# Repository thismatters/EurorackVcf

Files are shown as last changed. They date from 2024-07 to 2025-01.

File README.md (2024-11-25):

# Voltage Controlled Filter

The Voltage Controlled Filter (VCF) filters incoming audio signals to the degree specified by the control voltages. This implementation uses a transistor ladder similar to that found in Moog synthesizers with both a cutoff frequency and a resonator control.

The circuit here is based on the [MiniMoog VCF](https://yusynth.net/Modular/EN/MOOGVCF/index.html) with minor tweaks to make it more Eurorack friendly. The changes I've made are thus:
* Selected resistors appropriate for +/-12V rails,
* Added polarity protection so that a backward power header doesn't fry anything (twin series schotty diodes: BAT54SL),
* Selected a modern dual NPN diode package for matched transistors,
* Full surface mount design.

The Yusynth page is a treasure trove of information about this circuit that I am too amateur to claim as my own; please read that outstanding page before using this circuit. The page provides many details and other implementations of this circuit that you may find suitable.

The KiCAD project here uses the library/footprints [found in my companion repo](https://github.com/thismatters/EurorackKiCAD).

## Width

8hp on a standard 3U rack.

## Inputs

Potentiometer labeled `cutoff` controls the cutoff frequency, which is also augmented by the `cv1` input and potentiometer. Two other CV inputs `cv2` and `cv3` combine with `cv1` and the `cutoff` knob to set the frequency. An additional potentiometer for setting the `emph`asis. Two audio signal inputs, `in1` and `in2` are adjusted for level by twin potentiometers and combine as the audio input to the filter.

## Output

A single output labeled `out` yields the filtered audio signal.

## Adjustment

### Volt per Octave tracking

1. Set the `cutoff` knob to its minimum setting (counterclockwise).
1. Set the `emph` knob to its minimum setting (counterclockwise).
1. Apply 0V to `cv2`.
1. Measure 0mV at the test point `TP1`.
1. Apply 1V to `cv2`.
1. Adjust RV6 to measure 18.2mV at `TP1`.
1. Apply 5V to `cv2`.
1. Adjust RV6 to measure 91mV at `TP1`.
1. Set the `emph` knob to its maximum setting (auto oscillation).
1. Connect a keyboard to `cv2` and play a scale.
1. Adjust RV6 to achieve good chromatic tracking.

### Frequency Range

1. Apply a 32Hz sine wave to `in1`.
1. Set the `emph` knob to its minimum setting.
1. Set the `cutoff` knob to its minimum setting.
1. Adjust RV7 until the 32Hz tone is muted.

### Emphasis

1. Adjust RV8 in order to reach auto-oscillation near 95% of the full range of the `emph` potentiometer.

## Vendors

There are part numbers in the [BOM](moog-vcf.csv) for many of the parts (not for basic passives though) at the following vendors:

* [Mouser](https://www.mouser.com): Needs no introduction. Get your ICs from here (or [digikey](https://www.digikey.com)).
* [Tayda Electronics](https://www.taydaelectronics.com/): Good supplier for passive components; audio jacks, and potentiometers. Their audio jacks are slightly smaller than the thonkiconn from thonk.
* [Love My Switches](https://lovemyswitches.com/): Has [really good knobs](https://lovemyswitches.com/anodized-aluminum-knob-the-lo-fi-1-4-smooth-shaft-12-5mm-od/) to go on those potentiometers!
* [OSHPark](https://oshpark.com/): Fast and (relatively) cheap PCB manufacturer. The [V0 Circuit](https://oshpark.com/shared_projects/SO7swty4) works pretty well.

## Known Bugs

### v0

* Vias on Q5 (B1 and B2) block pads. (doesn't prohibit function)
* C8 hole pitch too narrow (should be 3mm)

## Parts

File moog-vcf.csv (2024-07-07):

# | Reference | Qty | Value | Footprint | DNP | Vendor | PartNum
1 | C1, C2 | 2 | 22u 35V | Capacitor_THT:CP_Radial_D5.0mm_P2.50mm
2 | C3, C11, C12 | 3 | 10u | Capacitor_THT:CP_Radial_D5.0mm_P2.50mm
3 | C4, C5, C6, C7 | 4 | 47n | Capacitor_SMD:C_0805_2012Metric
4 | C8 | 1 | 220u | Capacitor_THT:CP_Radial_D8.0mm_P2.50mm
5 | C9, C10 | 2 | 220n | Capacitor_SMD:C_0805_2012Metric
6 | C13 | 1 | 100n | Capacitor_SMD:C_0805_2012Metric
7 | C14 | 1 | 100p | Capacitor_SMD:C_0805_2012Metric
8 | D1, D2 | 2 | BAT54S | Package_TO_SOT_SMD:SOT-23 |  | Mouser | 863-BAT54SLT1G
9 | J1 | 1 | Conn_02x05_Odd_Even | Eurorack:PinHeader_2x05_P2.54mm_Vertical |  | Tayda | A-2939
10 | J2, J3, J4, J5, J6, J7 | 6 | AudioJack2_SwitchT | Eurorack:AudioJack2_Tayda_A-2566 |  | Tayda | A-2566
11 | Q1, Q2, Q3, Q4, Q5, Q6, Q7 | 7 | BCM847 | Package_SO:TSOP-6_1.65x3.05mm_P0.95mm |  | Mouser | 771-BCM847DS135
12 | Q8 | 1 | BC557 | Package_TO_SOT_THT:TO-92L_Inline_Wide |  | Mouser | 637-BC557B
13 | Q9 | 1 | BC547 | Package_TO_SOT_THT:TO-92L_Inline_Wide |  | Mouser | 637-BC547C
14 | R1, R2 | 2 | 10 | Resistor_SMD:R_0805_2012Metric
15 | R3, R4, R32 | 3 | 120K | Resistor_SMD:R_0805_2012Metric
16 | R5, R31 | 2 | 56K | Resistor_SMD:R_0805_2012Metric
17 | R6 | 1 | 10K | Resistor_SMD:R_0805_2012Metric
18 | R7, R8, R9, R13 | 4 | 100K | Resistor_SMD:R_0805_2012Metric
19 | R10 | 1 | 150K | Resistor_SMD:R_0805_2012Metric
20 | R11 | 1 | 1.8K | Resistor_SMD:R_0805_2012Metric
21 | R12, R15 | 2 | 470 | Resistor_SMD:R_0805_2012Metric
22 | R14 | 1 | 220 | Resistor_SMD:R_0805_2012Metric
23 | R16, R26, R28, R33 | 4 | 1K | Resistor_SMD:R_0805_2012Metric
24 | R17, R19, R20, R21 | 4 | 150 | Resistor_SMD:R_0805_2012Metric
25 | R18, R22 | 2 | 330 | Resistor_SMD:R_0805_2012Metric
26 | R23, R30 | 2 | 47K | Resistor_SMD:R_0805_2012Metric
27 | R24, R27 | 2 | 220K | Resistor_SMD:R_0805_2012Metric
28 | R25 | 1 | 22 | Resistor_SMD:R_0805_2012Metric
29 | R29 | 1 | 180 | Resistor_SMD:R_0805_2012Metric
30 | R34 | 1 | 680 | Resistor_SMD:R_0805_2012Metric
31 | RV1, RV2 | 2 | A50K | Eurorack:Potentiometer_RV16AF-41-15R1 |  | Tayda | A-4182
32 | RV3 | 1 | B50K | Eurorack:Potentiometer_RV16AF-41-15R1 |  | Tayda | A-2393
33 | RV4 | 1 | B10K | Eurorack:Potentiometer_RV16AF-41-15R1 |  | Tayda | A-2969
34 | RV5 | 1 | C50K | Eurorack:Potentiometer_RV16AF-41-15R1 |  | Tayda | A-4181
35 | RV6 | 1 | 500 | Potentiometer_THT:Potentiometer_Bourns_3296W_Vertical
36 | RV7 | 1 | 10K | Potentiometer_THT:Potentiometer_Bourns_3296W_Vertical
37 | RV8 | 1 | 1K | Potentiometer_THT:Potentiometer_Bourns_3296W_Vertical
38 | TP1 | 1 | TestPoint | TestPoint:TestPoint_THTPad_D2.0mm_Drill1.0mm
39 | U1 | 1 | TL072 | Package_SO:SOIC-8_3.9x4.9mm_P1.27mm |  | Mouser | 595-TL072CDR

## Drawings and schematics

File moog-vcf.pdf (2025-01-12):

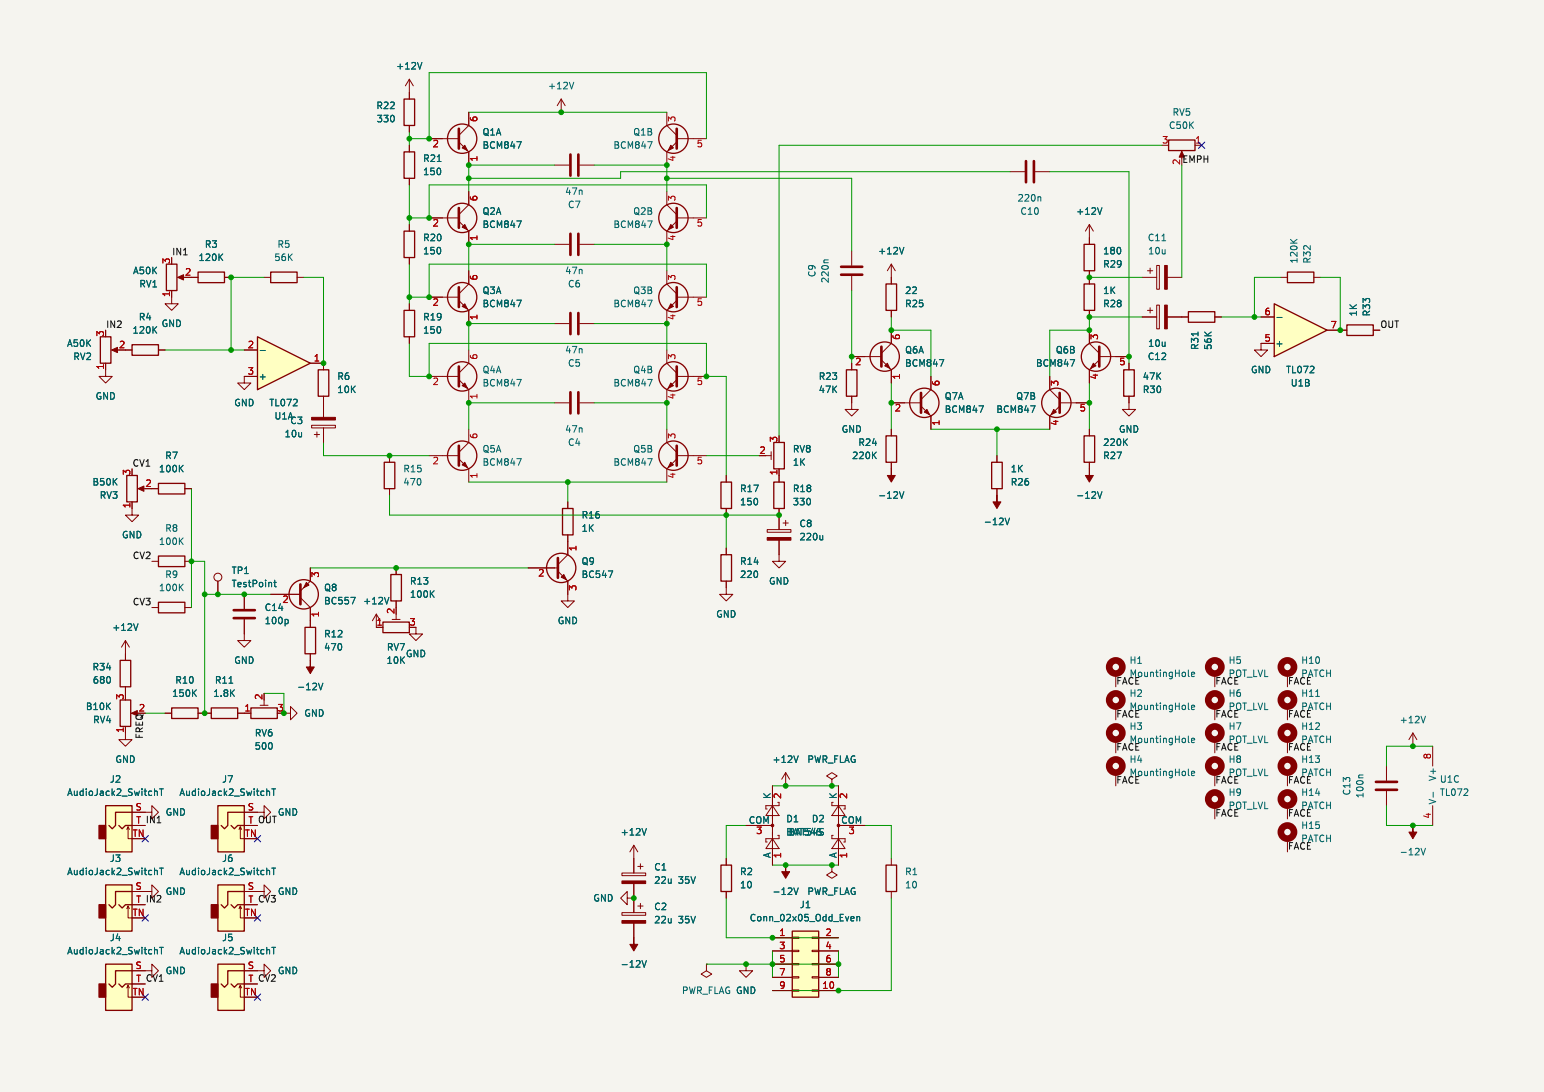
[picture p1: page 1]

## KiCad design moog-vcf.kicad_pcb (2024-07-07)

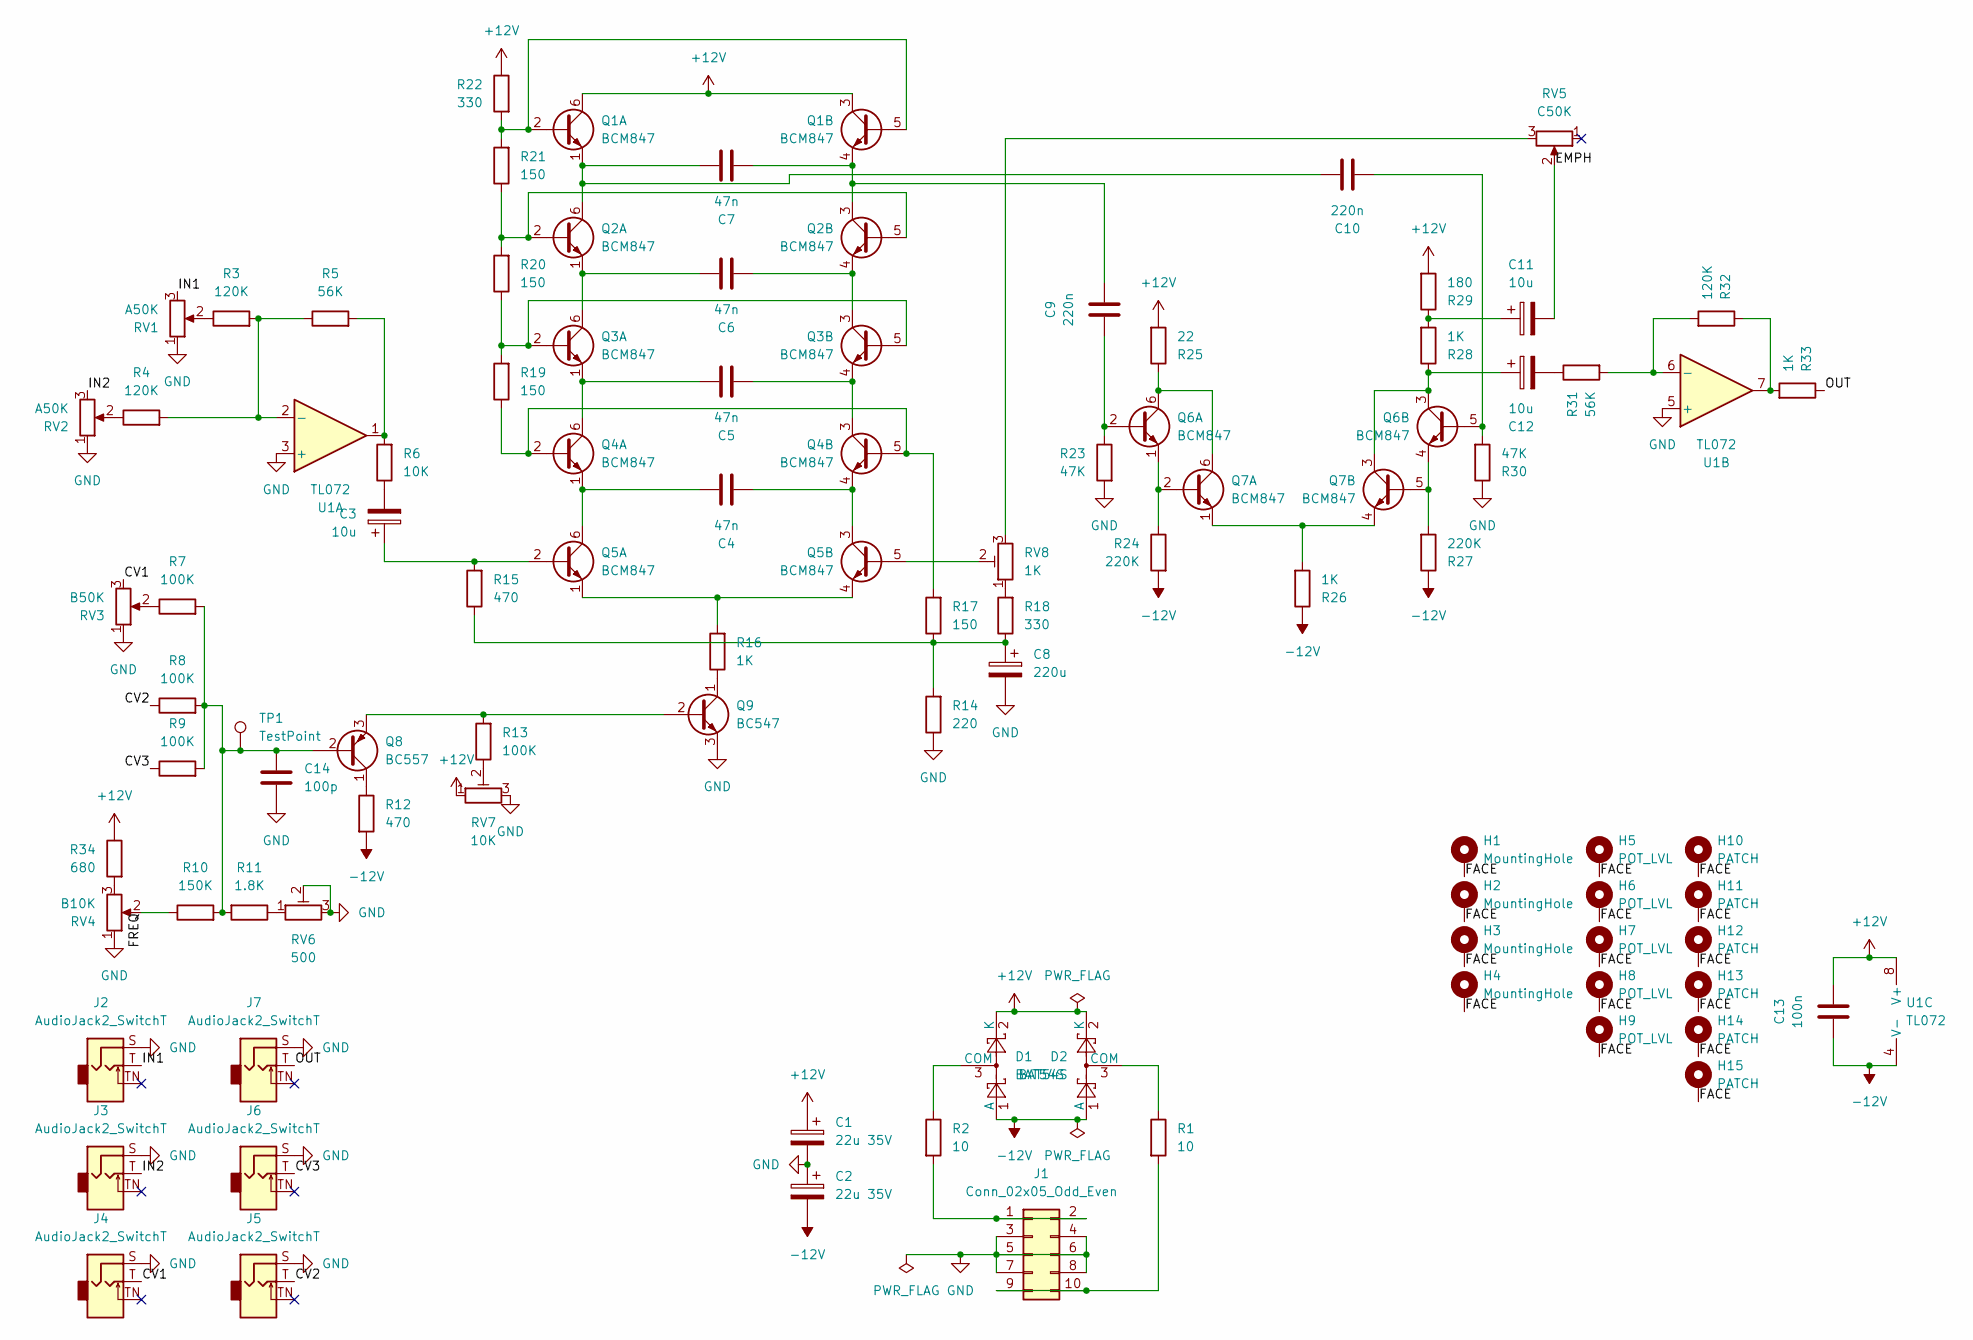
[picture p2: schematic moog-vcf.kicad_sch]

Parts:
C1, C2: 22u 35V; CP_Radial_D5.0mm_P2.50mm
C3, C11, C12: 10u; CP_Radial_D5.0mm_P2.50mm
C4, C5, C6, C7: 47n; C_0805_2012Metric
C8: 220u; CP_Radial_D8.0mm_P2.50mm
C9, C10: 220n; C_0805_2012Metric
C13: 100n; C_0805_2012Metric
C14: 100p; C_0805_2012Metric
D1, D2: BAT54S; SOT-23; PartNum 863-BAT54SLT1G
H1, H2, H3, H4: MountingHole; Mech-MountingHole
H5, H6, H7, H8, H9: POT_LVL; Mech-Potentiometer-Hole_level
H10, H11, H12, H13, H14: PATCH; Mech-AudioJack-Hole
H15: PATCH; Mech-AudioJack-Hole-Output
J1: Conn_02x05_Odd_Even; PinHeader_2x05_P2.54mm_Vertical; PartNum A-2939
J2, J3, J4, J5, J6, J7: AudioJack2_SwitchT; AudioJack2_Tayda_A-2566; PartNum A-2566
Q1, Q2, Q3, Q4, Q5, Q6, Q7: BCM847; TSOP-6_1.65x3.05mm_P0.95mm; PartNum 771-BCM847DS135
Q8: BC557; TO-92L_Inline_Wide; PartNum 637-BC557B
Q9: BC547; TO-92L_Inline_Wide; PartNum 637-BC547C
R1, R2: 10; R_0805_2012Metric
R3, R4, R32: 120K; R_0805_2012Metric
R5, R31: 56K; R_0805_2012Metric
R6: 10K; R_0805_2012Metric
R7, R8, R9, R13: 100K; R_0805_2012Metric
R10: 150K; R_0805_2012Metric
R11: 1.8K; R_0805_2012Metric
R12, R15: 470; R_0805_2012Metric
R14: 220; R_0805_2012Metric
R16, R26, R28, R33: 1K; R_0805_2012Metric
R17, R19, R20, R21: 150; R_0805_2012Metric
R18, R22: 330; R_0805_2012Metric
R23, R30: 47K; R_0805_2012Metric
R24, R27: 220K; R_0805_2012Metric
R25: 22; R_0805_2012Metric
R29: 180; R_0805_2012Metric
R34: 680; R_0805_2012Metric
RV1, RV2: A50K; Potentiometer_RV16AF-41-15R1; PartNum A-4182
RV3: B50K; Potentiometer_RV16AF-41-15R1; PartNum A-2393
RV4: B10K; Potentiometer_RV16AF-41-15R1; PartNum A-2969
RV5: C50K; Potentiometer_RV16AF-41-15R1; PartNum A-4181
RV6: 500; Potentiometer_Bourns_3296W_Vertical
RV7: 10K; Potentiometer_Bourns_3296W_Vertical
RV8: 1K; Potentiometer_Bourns_3296W_Vertical
TP1: TestPoint; TestPoint_THTPad_D2.0mm_Drill1.0mm
U1: TL072; SOIC-8_3.9x4.9mm_P1.27mm; PartNum 595-TL072CDR

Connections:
+12V: C1.1, C13.1, D1.2 (K), D2.2 (K), Q1.3 (C2), Q1.6 (C1), R22.1, R25.2, R29.2, R34.1, RV7.1, U1.8 (V+)
-12V: C2.2, C13.2, D1.1 (A), D2.1 (A), R12.2, R24.2, R26.1, R27.1, U1.4 (V-)
/CV1: J4.T, RV3.3
/CV2: J5.T, R8.1
/CV3: J6.T, R9.1
/EMPH: C11.2, RV5.2
/FACE: H1.1, H2.1, H3.1, H4.1, H5.1, H6.1, H7.1, H8.1, H9.1, H10.1, H11.1, H12.1, H13.1, H14.1, H15.1
/FREQ: R10.1, RV4.2
/IN1: J2.T, RV1.3
/IN2: J3.T, RV2.3
/OUT: J7.T, R33.1
GND: C1.2, C2.1, C8.2, C14.2, J1.3, J1.4, J1.5, J1.6, J1.7, J1.8, J2.S, J3.S, J4.S, J5.S, J6.S, J7.S, Q9.3 (E), R14.1, R23.2, R30.1, RV1.1, RV2.1, RV3.1, RV4.1, RV6.2, RV6.3, RV7.3, U1.3 (+), U1.5 (+)
unnamed: C3.2, R6.1
unnamed: C8.1, R14.2, R15.1, R17.1, R18.1
unnamed: C11.1, R28.2, R29.1
unnamed: C12.2, R31.1
unnamed: D1.3 (COM), R2.1
unnamed: D2.3 (COM), R1.1
unnamed: J1.1, J1.2, R2.2
unnamed: J1.9, J1.10, R1.2
unnamed: Q1.2 (B1), Q1.5 (B2), R21.2, R22.2
unnamed: C7.1, C10.1, Q1.1 (E1), Q2.6 (C1)
unnamed: C7.2, C9.1, Q1.4 (E2), Q2.3 (C2)
unnamed: Q2.2 (B1), Q2.5 (B2), R20.2, R21.1
unnamed: C6.1, Q2.1 (E1), Q3.6 (C1)
unnamed: C6.2, Q2.4 (E2), Q3.3 (C2)
unnamed: Q3.2 (B1), Q3.5 (B2), R19.2, R20.1
unnamed: C5.1, Q3.1 (E1), Q4.6 (C1)
unnamed: C5.2, Q3.4 (E2), Q4.3 (C2)
unnamed: Q4.2 (B1), Q4.5 (B2), R17.2, R19.1
unnamed: C4.1, Q4.1 (E1), Q5.6 (C1)
unnamed: C4.2, Q4.4 (E2), Q5.3 (C2)
unnamed: C3.1, Q5.2 (B1), R15.2
unnamed: Q5.1 (E1), Q5.4 (E2), R16.2
unnamed: Q5.5 (B2), RV8.2
unnamed: C9.2, Q6.2 (B1), R23.1
unnamed: Q6.6 (C1), Q7.6 (C1), R25.1
unnamed: Q6.1 (E1), Q7.2 (B1), R24.1
unnamed: C10.2, Q6.5 (B2), R30.2
unnamed: C12.1, Q6.3 (C2), Q7.3 (C2), R28.1
unnamed: Q6.4 (E2), Q7.5 (B2), R27.2
unnamed: Q7.1 (E1), Q7.4 (E2), R26.2
unnamed: C14.1, Q8.2 (B), R7.2, R8.2, R9.2, R10.2, R11.2, TP1.1
unnamed: Q8.1 (C), R12.1
unnamed: Q8.3 (E), Q9.2 (B), R13.2
unnamed: Q9.1 (C), R16.1
unnamed: R3.1, RV1.2
unnamed: R4.1, RV2.2
unnamed: R5.2, R6.2, U1.1
unnamed: R7.1, RV3.2
unnamed: R11.1, RV6.1
unnamed: R13.1, RV7.2
unnamed: R18.2, RV8.1
unnamed: R32.1, R33.2, U1.7
unnamed: R34.2, RV4.3
unnamed: RV5.3, RV8.3
unnamed: R3.2, R4.2, R5.1, U1.2 (-)
unnamed: R31.2, R32.2, U1.6 (-)

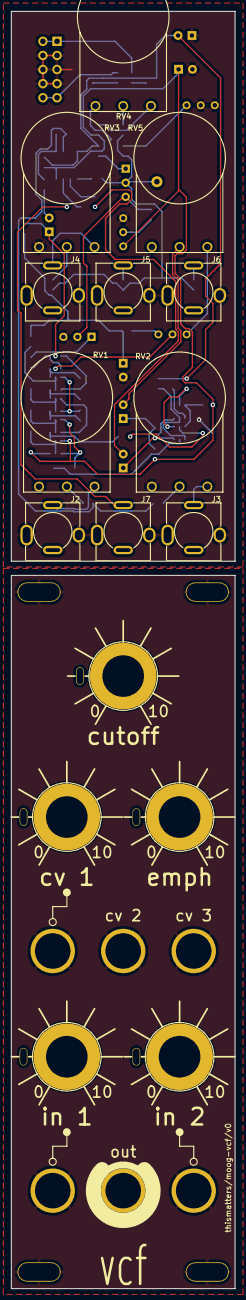
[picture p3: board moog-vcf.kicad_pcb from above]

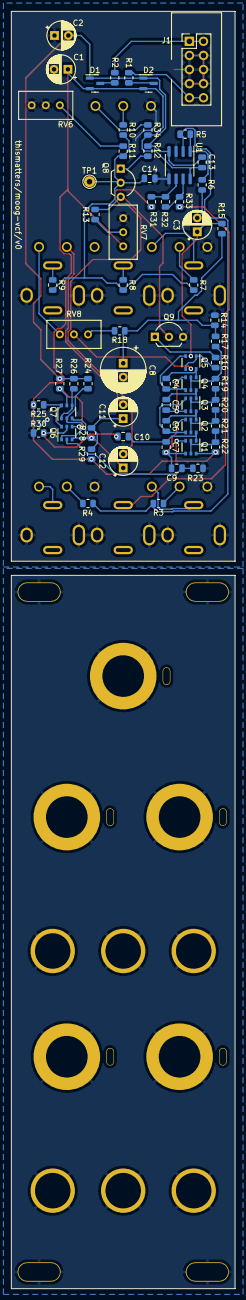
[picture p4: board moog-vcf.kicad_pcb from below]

Board: 2 copper layers, 40.3 x 230.1 mm, 91 parts (65 on the bottom side), 58 nets.

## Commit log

2024-08-11 adding known bugs from prototype build
2024-11-25 adding pcb to readme
2025-01-12 adding schematic
